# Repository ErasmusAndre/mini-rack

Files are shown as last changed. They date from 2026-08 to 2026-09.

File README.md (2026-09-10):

# mini-rack

The hardware behind [erasmus.works](https://github.com/ErasmusAndre/erasmus.works):
a custom-built 10-inch aluminium mini rack, 3D printed mounts and mains
distribution, and the mini-PCs running my Talos Kubernetes cluster.

<table>
<tr>
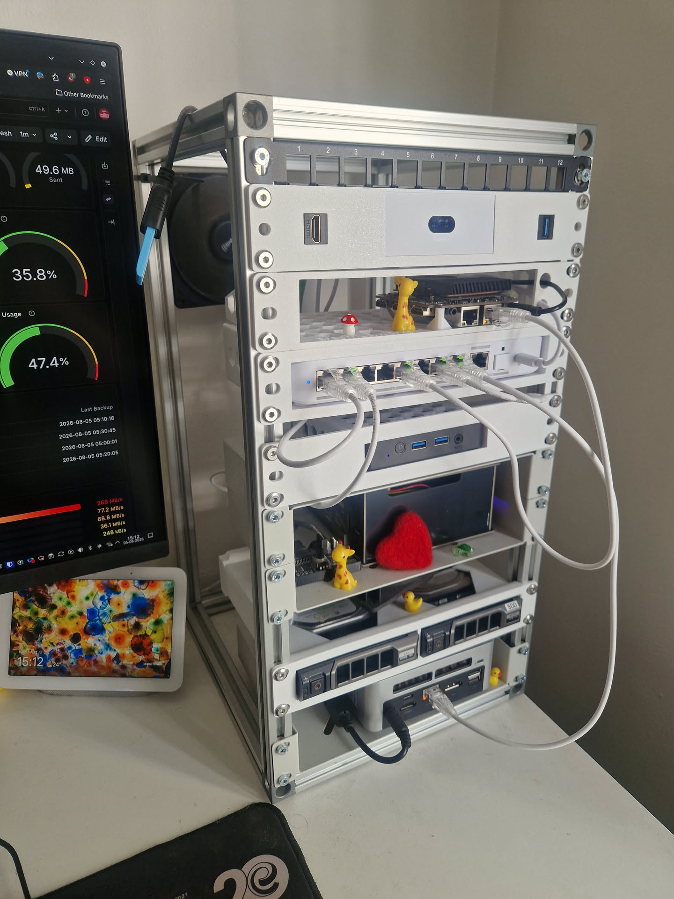
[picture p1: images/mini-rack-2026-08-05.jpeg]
The assembled rack, patch panel at the top down to the nodes and NAS at the bottom
<td width="50%"></td>
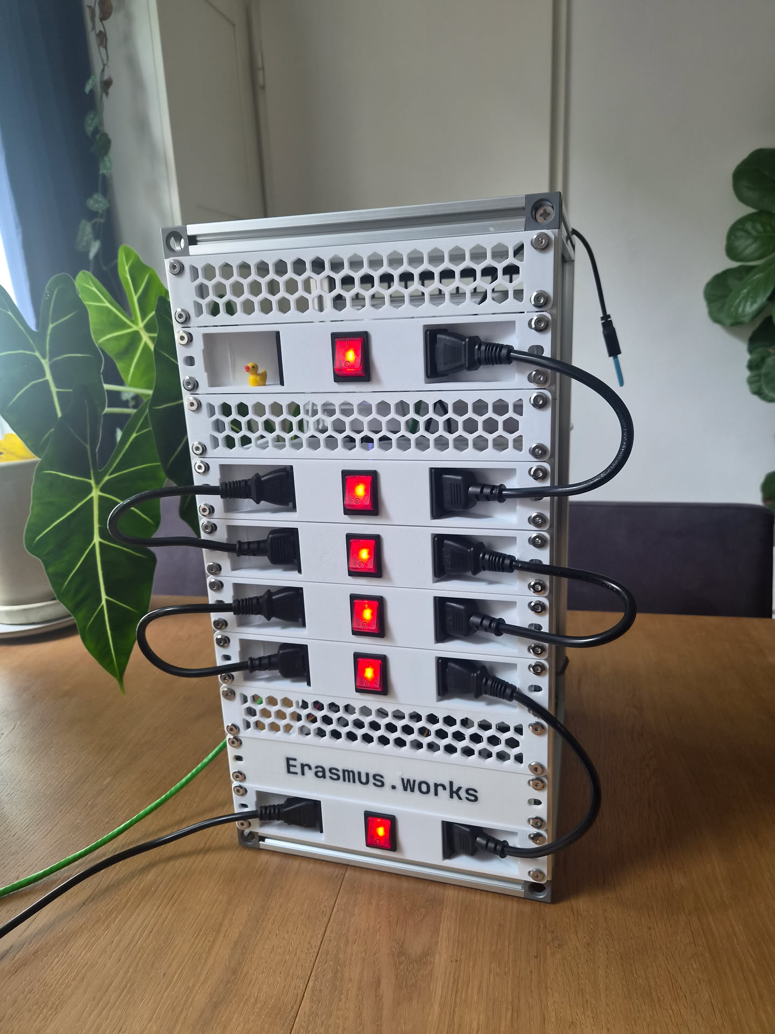
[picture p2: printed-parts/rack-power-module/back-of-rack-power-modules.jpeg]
Six power modules in the back of the rack, rockers lit red, a short cord looping from each module to the one below
<td width="50%"></td>
</tr>
</table>

---

## The Rack

2020 aluminium extrusion, 10U, 220 mm wide and 240 mm deep.

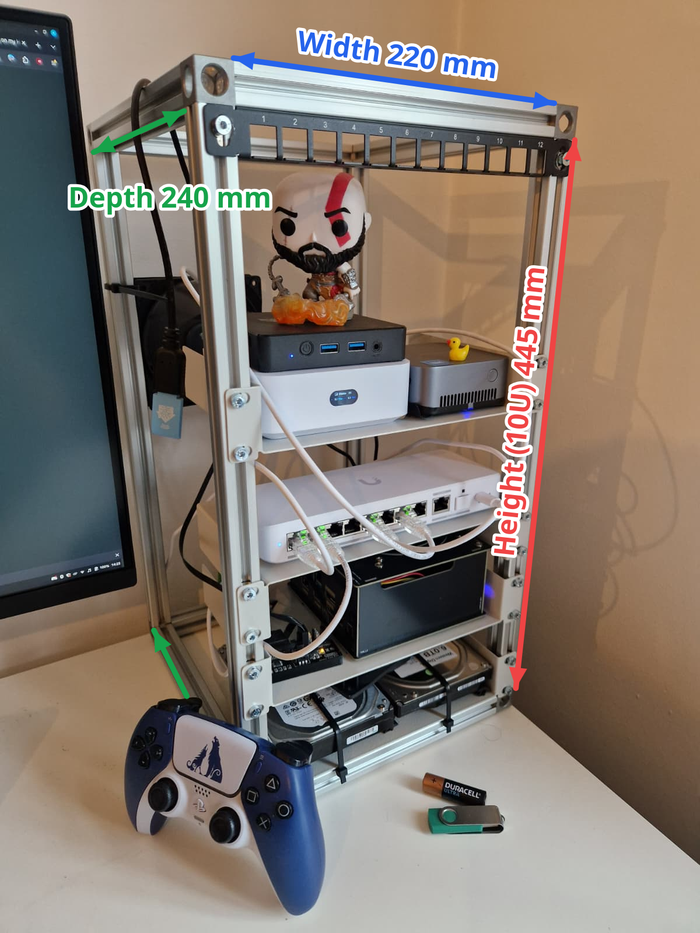
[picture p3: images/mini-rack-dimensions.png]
The rack frame with width 220 mm, depth 240 mm, and 10U height 445 mm marked


*PS5 controller, AA battery and USB stick for scale.*

### Parts

| Qty | Part | Price |
| --- | --- | --- |
| 4 | [Profile 20x20 B-type slot 6](https://www.motedis.nl/en/Profile-20x20-B-type-slot-6), 1 m lengths | €23.00 |
| 8 | [Cube connector 20 B-type slot 6](https://www.motedis.nl/en/Cube-connector-20-B-type-slot-6), 3D variant | €33.00 |
| 40 | [Roll-in T-slot nut, slot 6, M5](https://www.aluxprofiel.nl/inklikmoer-t-sleuf-6-m5/a3665), 4 per U | €10.00 |
| 40 | [Flanged button head screw DIN 7380F, M5x8](https://www.motedis.nl/nl/Flensbout-DIN-7380F/M5x8), one per T-nut | €9.00 |
| | **Total** | **€75.00** |

#### Notes on the Parts:

Slot 6 throughout, which is the common choice at this profile size and carries by
far the widest range of T-nuts and connectors. 
Note: Slot 5 profile and connectors are not interchangeable with these.

Take the 3D connectors, not 2D: every corner of a cuboid frame joins three
profiles. They ship with DIN965 M6x16 countersunk screws, one per profile.

The T-nuts roll into an assembled frame, so mounting points can be added later
without taking the rack apart. Order spares, they are 20 cents each. M5 here is
the nut thread and is unrelated to the profile's M6 core.

The flange spreads load across the slot edges, so no washer is needed in normal
use. M5x8 suits 3 to 5 mm printed parts. For thinner mounts such as 1.5 mm steel
shelves, add a washer or drop to a 6 mm bolt, otherwise the screw bottoms out
before it clamps.

### Cut list

Twelve pieces out of the four 1 m lengths:

| Qty | Length | Axis |
| --- | --- | --- |
| 4 | 220 mm | Width |
| 4 | 240 mm | Depth |
| 4 | 445 mm | Height |

A rack unit is 44.5 mm, so height is `44.5 x U`. This build is 10U: 44.5 x 10 = 445 mm.

Two 445 mm pieces come out of each of the first two lengths, four 240 mm out of
the third, four 220 mm out of the fourth. That is 3620 mm cut from 4000 mm, so
there is room for saw kerf and a mistake.

Depth is a free choice. 240 mm clears the mini-PCs used here with room for cabling
behind them.

<!-- TODO: rack ears and patch panel mounting. -->

## 3D Printed Parts

<!-- TODO: one row per part: what it mounts, filament, and print settings.
     Both exports live in printed-parts/, same basename: rack-ear.step (AP242, from
     Onshape) next to rack-ear.3mf (slicer project, carries the print settings,
     so link it rather than retyping them). Add the public Onshape doc link.
     Ship the STEP where there is one: it is the file people can actually
     edit. CC BY-NC-SA does not require it. -->

| Part | Mounts | Material | Files |
| --- | --- | --- | --- |
| [Blackview MP-80 10 inch rack mount](printed-parts/blackview-mp80-10inch-rack-mount/) | K8s Node 2, 1U on the rails | PLA | [STEP](printed-parts/blackview-mp80-10inch-rack-mount/Blackview-MP80-10inch-Rack-Mount.step) · [3MF](printed-parts/blackview-mp80-10inch-rack-mount/Blackview-MP80-10inch-Rack-Mount.3mf) |
| [Blackview MP-80 mount](printed-parts/blackview-mp80-mount/) | K8s Node 2, shelf test mount | PLA | [STEP](printed-parts/blackview-mp80-mount/Blackview-MP80-Mount.step) · [3MF](printed-parts/blackview-mp80-mount/Blackview-MP80-Mount.3mf) |
| [Rack power module](printed-parts/rack-power-module/) | Mains distribution, 1U on the rails | PLA | [3MF, both variants](printed-parts/rack-power-module/README.md#files) |

## Power

One printed module per device, stacked down the back of the rack. Each carries a
C14 inlet, an illuminated DPST rocker and a C13 outlet, with a honeycomb shelf
behind the face plate for the device's mains adapter. A 30 cm C13 to C14 cord
links each module to the one below, so the stack chains off a single feed and
each rocker cuts its own module and everything downstream.

Two variants share the same face plate. **DIN rail** takes a normal two pin wall
plug on a length of DIN rail. **Power brick** goes straight into the brick's C14
inlet on a right angle connector. Stacked, the sockets alternate left and right,
which leaves room for an adapter taller than 1U.

Each module is 1U at the rails and costs €16 to €18 in parts.

<table>
<tr>
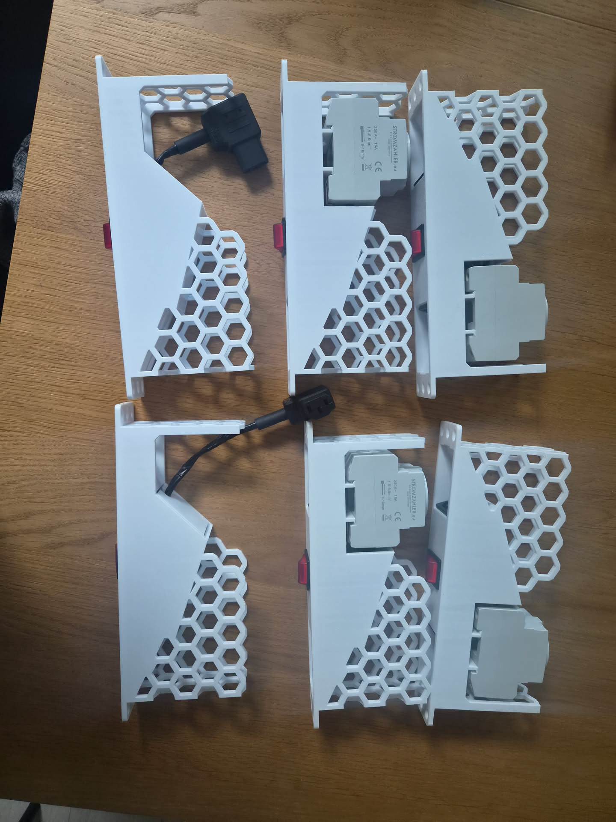
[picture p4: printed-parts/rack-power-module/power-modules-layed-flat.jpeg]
Six modules laid flat on a table, showing the face plate, the honeycomb side wall and the shelf, four with a DIN rail socket and two with a right angle C13 connector
<td width="50%"></td>
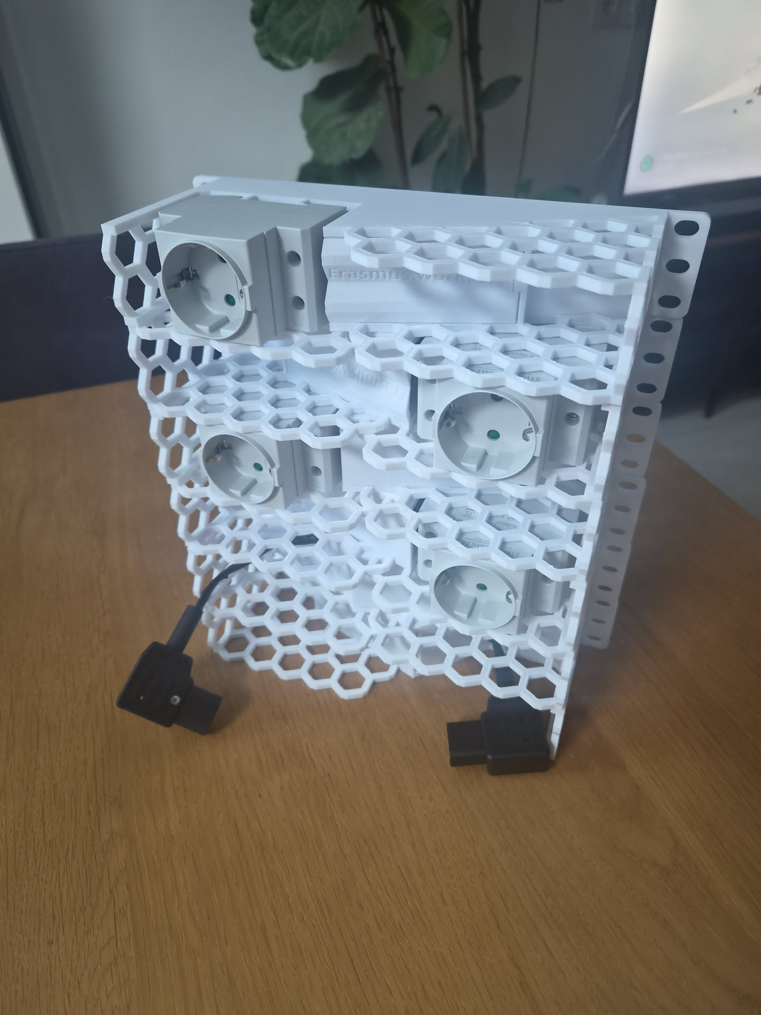
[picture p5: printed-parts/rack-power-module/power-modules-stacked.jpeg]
Four modules stacked, sockets alternating left and right down the stack, each clipped to the DIN rail behind the honeycomb shelf
<td width="50%"></td>
</tr>
</table>

This part carries live mains, which kills people who get it wrong. Do not build
it unless you are competent to wire mains and permitted to do so where you live.
Read [Safety](printed-parts/rack-power-module/README.md#safety) before you start,
and before you pick a filament.

Bill of materials, wiring diagram and build steps:
[Rack Power Module](printed-parts/rack-power-module/).

## Hardware

Compute currently in the cluster:

| Hardware | Model | CPU | Memory | Storage |
| --- | --- | --- | --- | --- |
| K8s Node 1 | MINIS FORUM UN1245 Mini-PC | Intel Core i5-12450H | 16 GB DDR4 | 512 GB SSD |
| K8s Node 2 | Blackview MP-80 | Intel Processor N97 | 16 GB DDR5 | 512 GB SSD |
| Home Assistant | BMAX B2 Pro | Intel Celeron N4000 | 8 GB DDR4 | 256 GB SSD |
| NAS | ODROID-H4+ | Intel Processor N97 | 16 GB DDR5 | 2 × 6 TB HDD |
| Router | UniFi Express 7 (UX7) | - | - | - |
| Switch | UniFi Flex 2.5G (USW-Flex-2.5G-8) | - | - | - |

---

## License

Star ⭐ this repo if you found it useful.

[CC BY-NC-SA 4.0](LICENSE). Use it, modify it, share it, as long as you credit
Erasmus.works, link back to this repo, keep it non-commercial, and license
anything you share under the same terms.

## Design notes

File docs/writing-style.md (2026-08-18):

# Writing style

Applies to every README, part doc, and comment in this repo.

## Length

Say it once. Cut any sentence that repeats, summarises, or softens the one
before it. If a section survives losing a sentence, lose it.

Document decisions and facts, not reasoning you can infer from the result. The
reader wants to print the part, not follow how it was designed.

## Preferred

Facts over descriptions of facts. Write "0.2 mm layers", not "a fairly standard
layer height".

Imperative for instructions. "Keep the OEM screws", not "you will want to keep
the OEM screws".

Three items in a list only when there are three things.

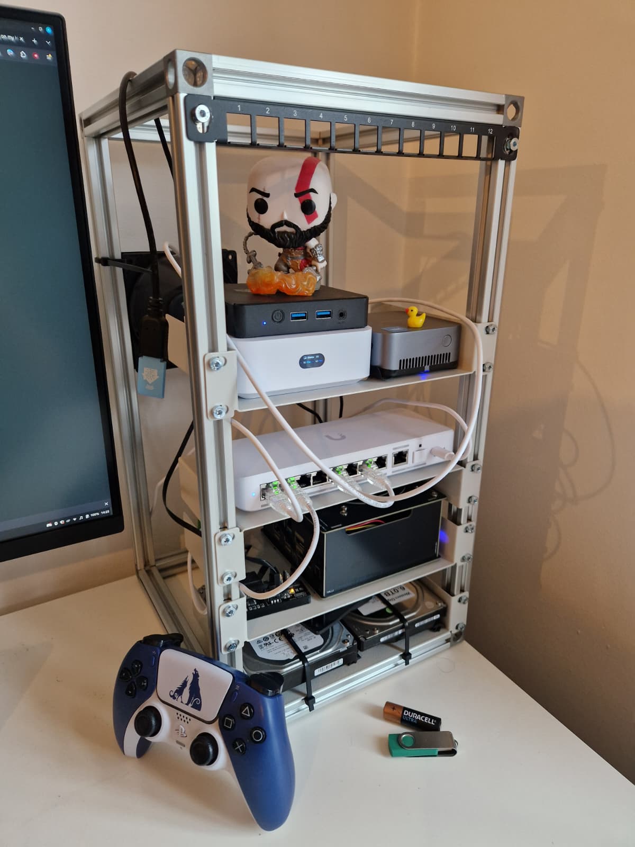
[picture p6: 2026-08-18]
images/mini-rack-2025-10-10.jpeg

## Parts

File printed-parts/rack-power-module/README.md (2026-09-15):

# Rack Power Module

A 10-inch rack part for mains distribution: one switched socket per module,
chained down the back of the rack.

Do not build this without reading [Safety](#safety) first.

Six power modules in the back of the rack, rockers lit red, a short cord looping from each module to the one below

## Design notes

These are the modules. Two variants, same face plate: C14 inlet, illuminated
rocker, C13 outlet, and a honeycomb shelf behind it for the mains adapter. A
30 cm C13 to C14 cord links each module to the next.

**Power brick**, the two at the left below: a rewireable right angle C13
connector, straight into the brick's C14 inlet.

**DIN rail**: a socket on a length of DIN rail, for a normal two pin wall
plug.

<table>
<tr>
<td width="50%">Six modules laid flat on a table, showing the face plate, the honeycomb side wall and the shelf, four with a DIN rail socket and two with a right angle C13 connector</td>
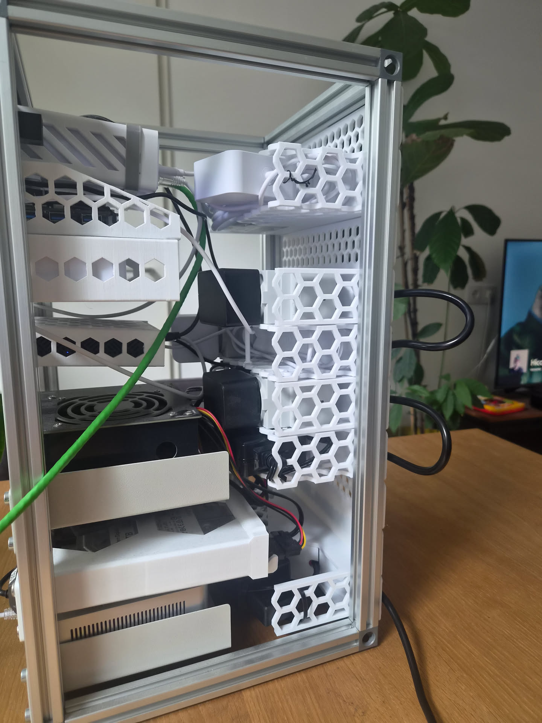
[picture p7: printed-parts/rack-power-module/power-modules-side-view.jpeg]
The rack from the side, power modules stacked down the right, adapters resting on the honeycomb shelves
<td width="50%"></td>
</tr>
</table>

Stacked, the sockets alternate left and right. A rack unit is 44.5 mm and some
wall plugs are taller than that, so the offset leaves room for a big one.

Both print files include a cable clip, a fork that pushes into the honeycomb.
Roll the slack up and hold it there.

Four modules stacked, sockets alternating left and right down the stack, each clipped to the DIN rail behind the honeycomb shelf

## Hardware

Per module:

| Qty | Part | Price | Mounting |
| --- | --- | --- | --- |
| 1 | [C13 to C14 cord, 30 cm](https://nl.rs-online.com/web/p/power-cords/1373334) (RS 1373334) | €4.95 | |
| 1 | [C14 inlet, snap-in](https://nl.rs-online.com/web/p/iec-connectors/5392023) (Schurter 6100.4320) | €1.15 | 27.5 × 20.0 mm cutout |
| 1 | [C13 outlet, snap-in](https://nl.rs-online.com/web/p/iec-connectors/5392152) (Schurter 6600.4315) | €2.15 | 32.5 × 24.8 mm cutout |
| 1 | [Illuminated DPST rocker](https://nl.rs-online.com/web/p/rocker-switches/7932507) (Molveno SX82) | €1.75 | 30 × 22 mm cutout |
| 8 | [Female faston, insulated, 0.5 to 1.5 mm²](https://nl.rs-online.com/web/p/spade-connectors/0534339) (RS 534-339) | €1.45 | 6.3 × 0.8 mm tabs |
| 0.6 m | H05VV-F 3G1.5 flexible cable | €0.80 | |
| | **Subtotal** | **€12.25** | |

Plus, per variant:

| Variant | Part | Price | Total |
| --- | --- | --- | --- |
| DIN rail | [DIN rail socket](https://stromzähler.eu/detail/018af08cc9277014a5bf7629857d9ec8) (B+G E-Tech) + 2 × [twin ferrule](https://nl.rs-online.com/web/p/bootlace-ferrules/1788742) (RS 178-8742) | €3.85 | €16.10 |
| Power brick | [C13 rewireable, right angle](https://nl.rs-online.com/web/p/iec-connectors/2825502) (RS 282-5502) + 2 × [butt splice](https://nl.rs-online.com/web/p/splice-connectors/2707457) (RS 270-7457) | €5.48 | €17.73 |

## Want to build this yourself?

1. Download the [print files](#files) and print what you need.
2. Star this repo ⭐
3. Clip in the C13 and C14 connectors, 2 prongs facing away from the face plate.
4. Alternate the rocker per module to keep every switch facing the same way.
5. Wire it up as in [Wiring](#wiring).
6. Clip in and wire up the DIN rail socket or the C13 plug.
7. Clip in the closing plates, short one first. Spread the honeycomb if it sticks.

## Wiring

Do not build this without reading [Safety](#safety) first.

Live and neutral both break at the rocker.

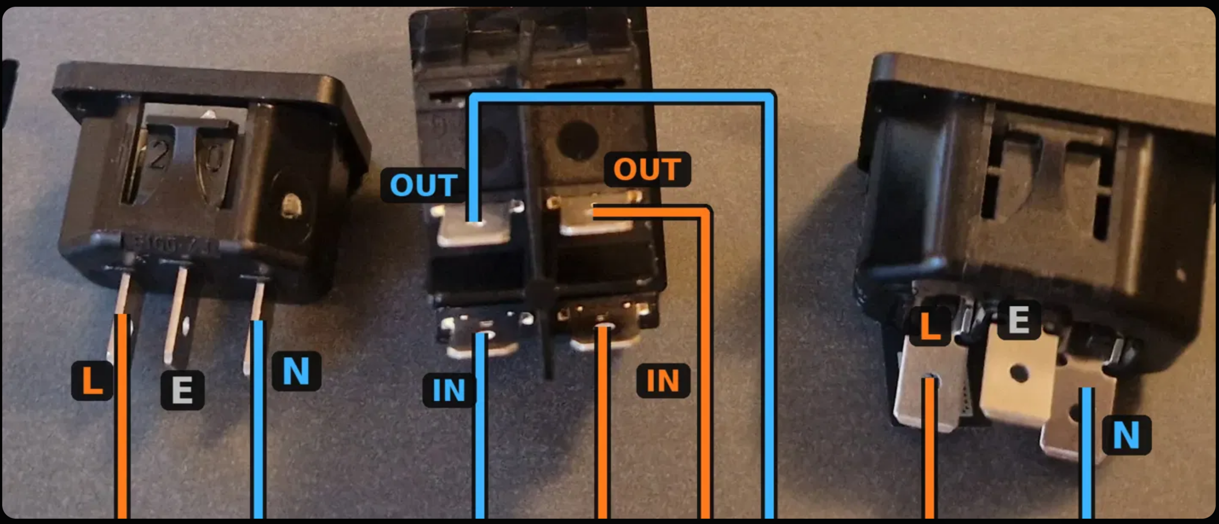
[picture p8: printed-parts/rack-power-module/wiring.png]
C14 inlet on the left, DPST rocker in the middle, C13 outlet on the right, live traced in orange and neutral in blue


Run live and neutral from the inlet to the rocker and nowhere else. Socket and
outlet both come off the switched side, so the rocker cuts this module and
everything downstream.

The socket splits off after the rocker: at the socket on the DIN rail variant,
two wires into one twin ferrule; mid lead on the power brick variant, at a butt
splice.

<table>
<tr>
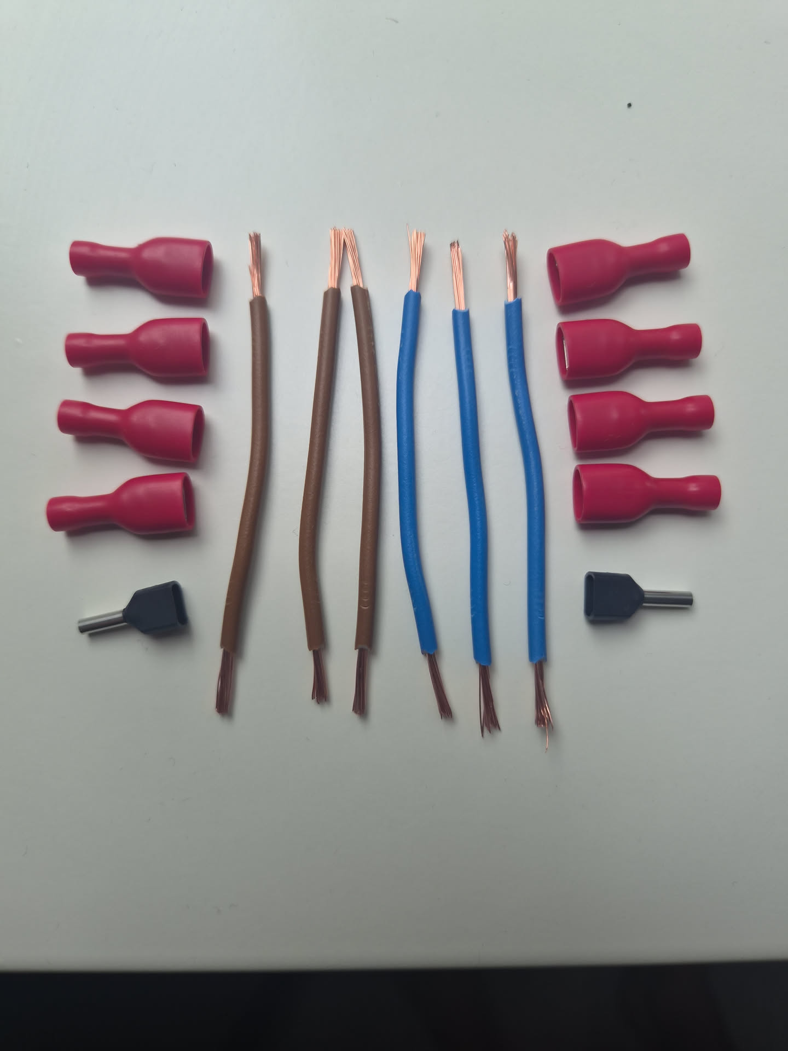
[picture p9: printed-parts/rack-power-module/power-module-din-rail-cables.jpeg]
Eight insulated female fastons, six short leads in brown and blue, and two twin ferrules
<td width="50%"></td>
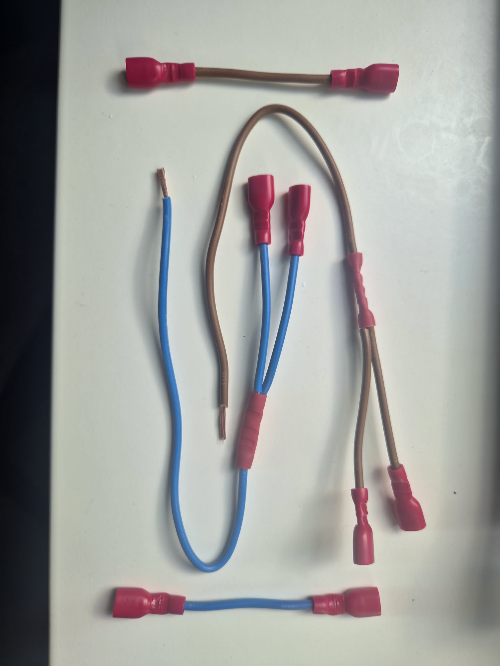
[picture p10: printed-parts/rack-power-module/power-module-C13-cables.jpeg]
Longer brown and blue leads crimped with insulated fastons, a red butt splice partway along the brown pair and another along the blue
<td width="50%"></td>
</tr>
<tr>
<td><em>DIN rail loom. Cut all six leads to 8 cm. Twin ferrules at the socket.</em></td>
<td><em>Power brick loom. Cut four leads to 8 cm and one to about 16 cm. Butt splices for the split.</em></td>
</tr>
</table>

Wired up, before the variant-specific parts go in, it looks like this.

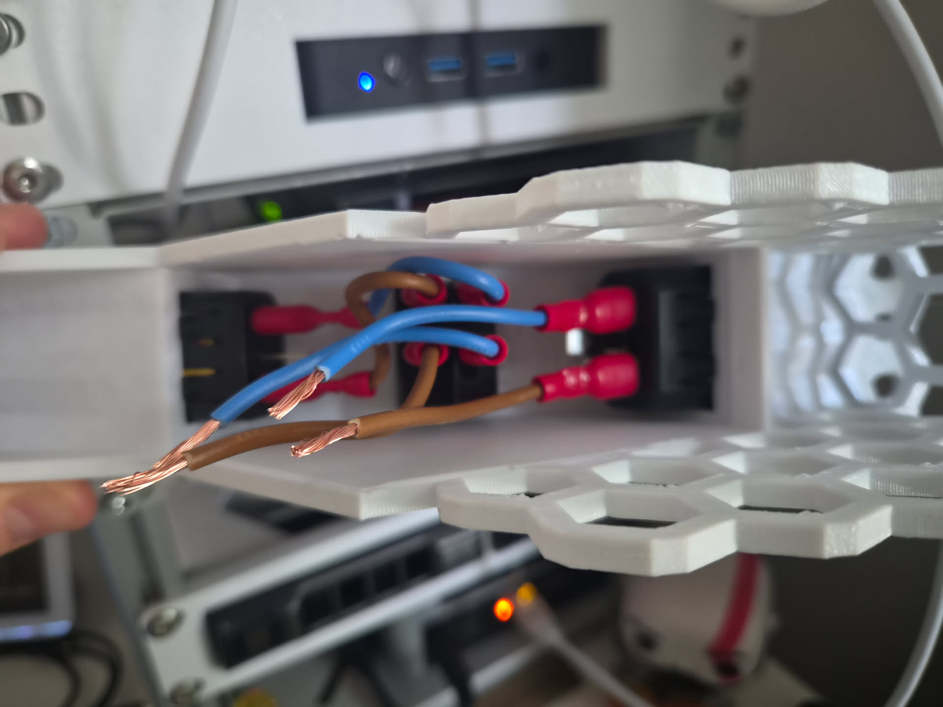
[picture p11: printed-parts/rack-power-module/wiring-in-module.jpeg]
The back of a face plate, brown and blue leads crimped onto the connectors and the rocker, free ends waiting for the socket or plug


Alternatively, wire the C13 outlet straight to the C14 inlet and only the socket
through the rocker. The rocker then cuts only what is plugged into this module,
and the modules chained below stay on.

### Daisy chaining

Every connection adds resistance. With quality parts and correct crimps it is
negligible: six chained modules measure 0.2 Ω, the same as a shop-bought rack
power strip. Both read 0.6 Ω on the meter, 0.2 Ω after subtracting 0.4 Ω for the leads.

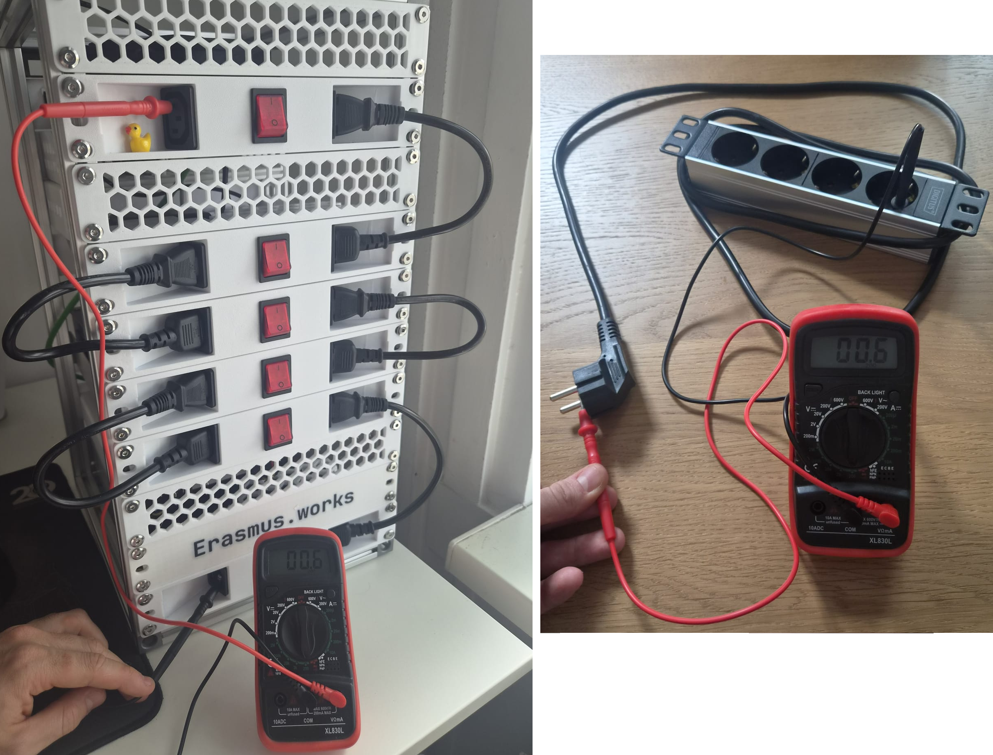
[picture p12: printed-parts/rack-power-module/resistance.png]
Left: a multimeter reading 0.6 Ω across six chained modules. Right: the same meter reading 0.6 Ω across a rack power strip, plug to socket


Measure the resistance before plugging anything in.

## Tools

- 3D printer
- Wire stripper and crimper
- Side cutters
- Long nose pliers
- Screwdriver
- Insulation tape

## Files

Print it in a flame retardent UL 94 V-0 filament such as
[PETG FR Jet](https://shop.filament-pm.com/petg-frjet-self-extinguishing-white-1-75-mm-0-5-kg/p166).

| Variant | File |
| --- | --- |
| DIN rail | [3MF](erasmus-works-power-module-din-rail-v62.3mf) |
| Power brick | [3MF](erasmus-works-power-module-power-brick-v62.3mf) |

## Safety

This part carries live mains. Mains wiring kills people who get it wrong, and a
fault in a printed enclosure can start a fire.

Do not build it unless you are competent to wire mains and permitted to do so
where you live. Sleeve or shroud all live terminals.
PLA softens around 60 °C, PETG around 80 °C. Neither is flame retardant. Only a
UL 94 V-0 filament is. Print it in a self-extinguishing filament such as
[PM PETG FR Jet](https://shop.filament-pm.com/petg-frjet-self-extinguishing-white-1-75-mm-0-5-kg/p166).

Wire the protective earth if anything you plug in needs it.

Every module draws its power through the ones before it, so the first module
carries the load of the whole chain. Keep the total under 10 A, 2300 W at
230 V: that is the rating of the C13 and C14 connectors and the 0.75 mm² cords.

Build it at your own risk. I take no responsibility for injury, death, fire, or
damage resulting from anything in this repository.

## License

Star ⭐ this repo if you found it useful.

[CC BY-NC-SA 4.0](../../LICENSE). Use it, modify it, share it, as long as you
credit Erasmus.works, link back to this repo, keep it non-commercial, and
license anything you share under the same terms.

This work is offered as is, WITHOUT WARRANTIES OR CONDITIONS OF ANY KIND,
express or implied. Please see the licence for applicable conditions.

Source location: https://github.com/ErasmusAndre/mini-rack

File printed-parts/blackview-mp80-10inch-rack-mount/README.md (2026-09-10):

# Blackview MP-80 10 inch Rack Mount

A 1U 10-inch tray for the Blackview MP-80 (K8s Node 2) with its OEM enclosure
stripped off, printed in white PLA.

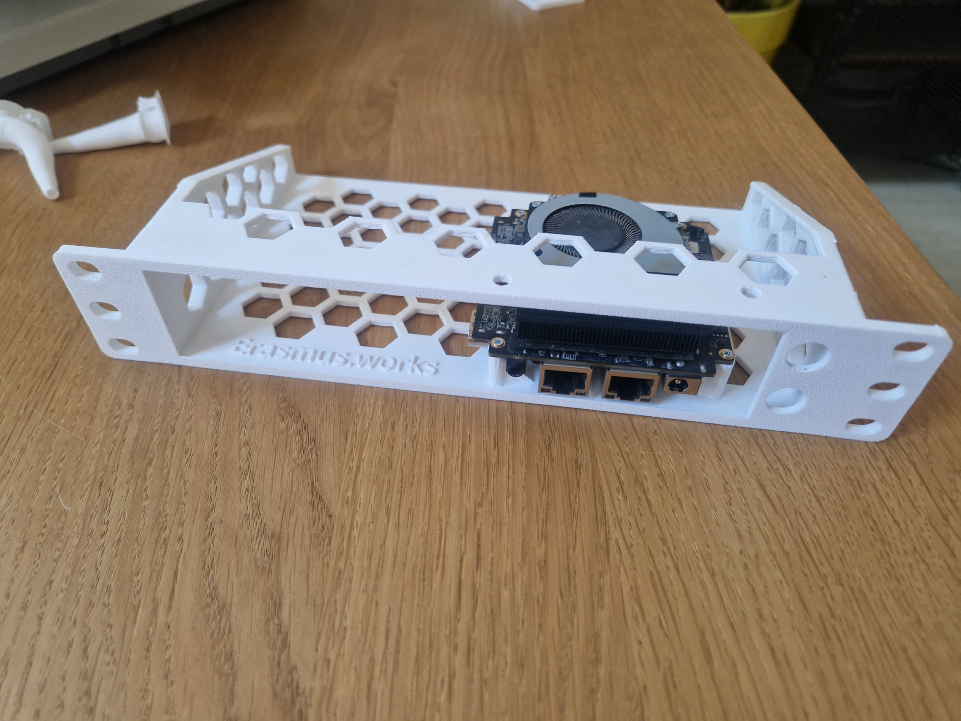
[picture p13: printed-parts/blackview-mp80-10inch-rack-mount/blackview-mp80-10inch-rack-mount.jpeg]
The printed tray on a desk with the bare MP-80 board bolted in


## Design notes

The board no longer sits on a shelf. This is what the
[test mount](../blackview-mp80-mount/) was a trial run for: the same board
profile, now folded into a full-width tray.

The MP-80 does not go in the rack in its OEM enclosure. The board comes out of
the case and bolts to the tray instead. Outside the sealed plastic shell the
heatsink sits in open air, so the node runs cooler.

The hex cutouts in the floor and side wall let air through and cut print time.
The front panel carries embossed Erasmus.works text, the files you can download in this repo don't. 

## Printing

Print the front panel face down on the bed, with tree supports.

## Hardware

| Qty | Part |
| --- | --- |
| 4 | Flanged button head DIN 7380F, M5x8, one per ear hole |
| 4 | Roll-in T-slot nut, slot 6, M5 |
| | The MP-80's own enclosure screws, salvaged when you strip the case |

## Files

| File | What it is |
| --- | --- |
| [`Blackview-MP80-10inch-Rack-Mount.step`](Blackview-MP80-10inch-Rack-Mount.step) | Source geometry, STEP AP242. Edit this. |
| [`Blackview-MP80-10inch-Rack-Mount.3mf`](Blackview-MP80-10inch-Rack-Mount.3mf) | Ready to slice and print. |

## License

Star ⭐ this repo if you found it useful.

[CC BY-NC-SA 4.0](../../LICENSE). Use it, modify it, share it, as long as you
credit Erasmus.works, link back to this repo, keep it non-commercial, and
license anything you share under the same terms.

This work is offered as is, WITHOUT WARRANTIES OR CONDITIONS OF ANY KIND,
express or implied. Please see the licence for applicable conditions.

Source location: https://github.com/ErasmusAndre/mini-rack

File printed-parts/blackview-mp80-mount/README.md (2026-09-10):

# Blackview MP-80 Mount

A stand for the Blackview MP-80 (K8s Node 2) with its OEM enclosure stripped
off, printed in green PLA.

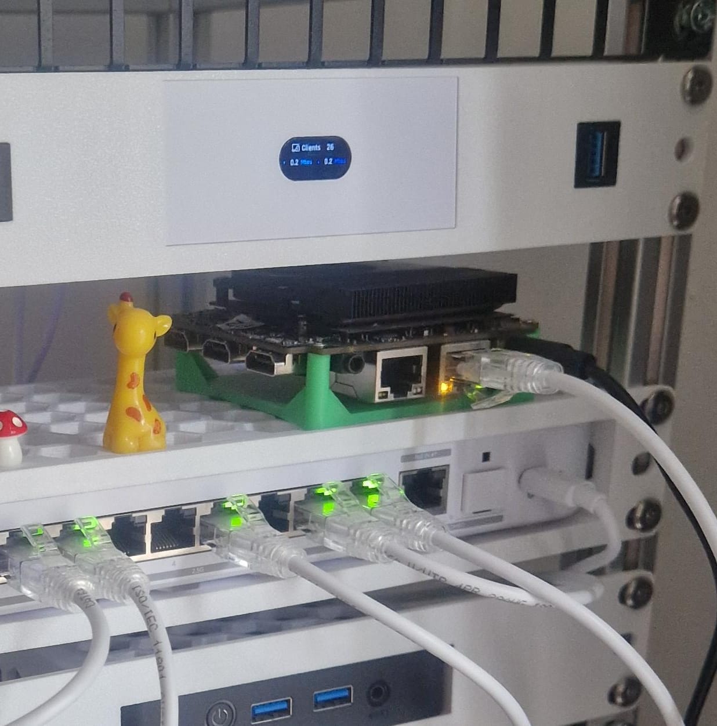
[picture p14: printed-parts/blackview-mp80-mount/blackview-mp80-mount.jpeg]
The mount in the rack, holding the bare MP-80 board


## Design notes

This is a test mount, not a finished part. It holds the board steady on a shelf
and nothing more. The profile was folded into the
[10 inch rack mount](../blackview-mp80-10inch-rack-mount/), which is what the
node runs in now.

The MP-80 does not go in the rack in its OEM enclosure. The board comes out of
the case and bolts to this stand instead. Outside the sealed plastic shell the
heatsink sits in open air, so the node runs cooler, and without the case it
takes up much less room on the shelf.

The screws that hold the board down come from the OEM enclosure, so keep them
when you take the case apart. Nothing else is needed.

## Printing

It lays flat on its bottom face and prints without supports.

## Hardware

The MP-80's own enclosure screws, salvaged when you strip the case. No other
fasteners.

## Files

| File | What it is |
| --- | --- |
| [`Blackview-MP80-Mount.step`](Blackview-MP80-Mount.step) | Source geometry, STEP AP242. Edit this. |
| [`Blackview-MP80-Mount.3mf`](Blackview-MP80-Mount.3mf) | Ready to slice and print. |

## License

Star ⭐ this repo if you found it useful.

[CC BY-NC-SA 4.0](../../LICENSE). Use it, modify it, share it, as long as you
credit Erasmus.works, link back to this repo, keep it non-commercial, and
license anything you share under the same terms.

This work is offered as is, WITHOUT WARRANTIES OR CONDITIONS OF ANY KIND,
express or implied. Please see the licence for applicable conditions.

Source location: https://github.com/ErasmusAndre/mini-rack

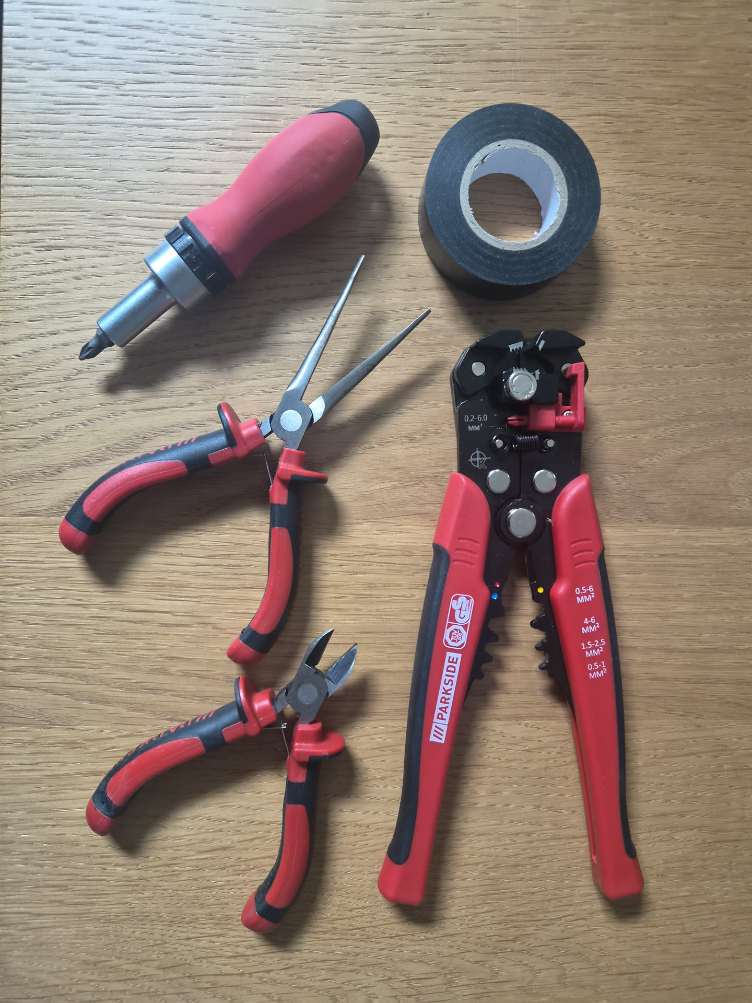
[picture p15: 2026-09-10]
printed-parts/rack-power-module/tools-needed.jpeg

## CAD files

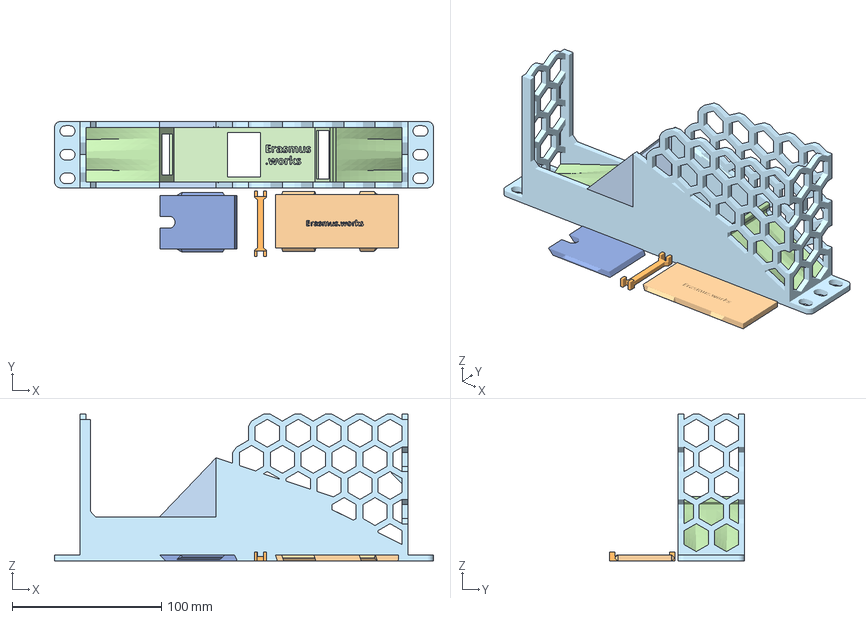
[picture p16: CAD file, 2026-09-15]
printed-parts/rack-power-module/erasmus-works-power-module-power-brick-v62.3mf
254.0 x 90.5 x 98.4 mm
Cable Clip
Mount Switch
right chamfer
Left power plate
Left chamfer
Mount C13
Mount C14
hinge plate
extend front plate
extend back plate
Face-Plate

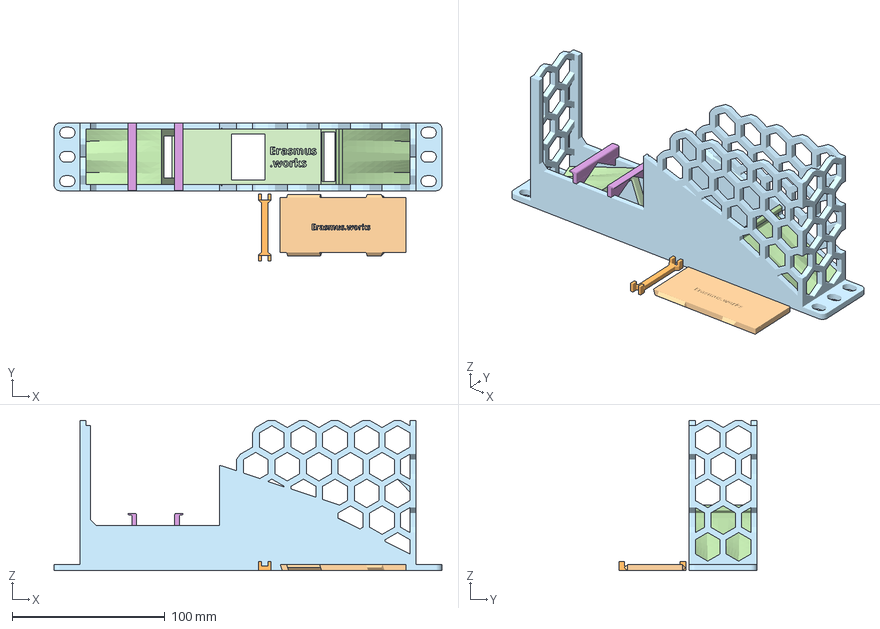
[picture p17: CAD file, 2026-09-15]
printed-parts/rack-power-module/erasmus-works-power-module-din-rail-v62.3mf
254.0 x 90.5 x 98.4 mm
DIN Rail right
DIN Rail left
Cable Clip
Mount Switch
right chamfer
Left chamfer
Mount C13
Mount C14
Face-Plate
hinge plate

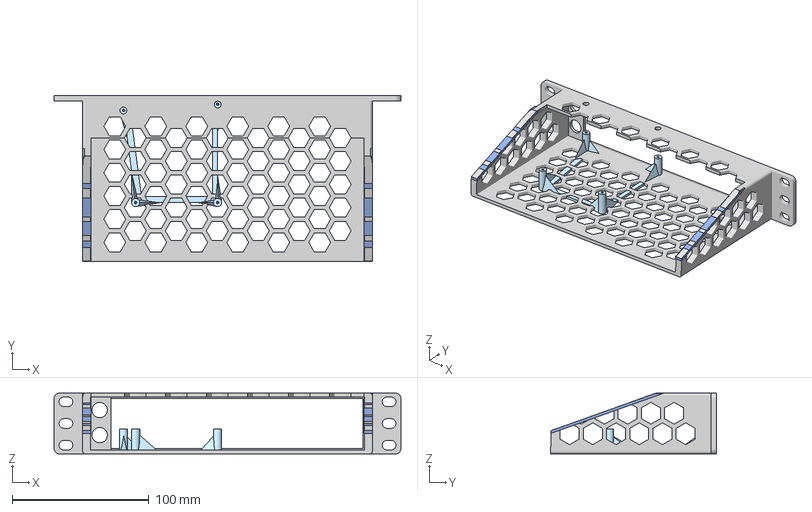
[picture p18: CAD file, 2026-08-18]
printed-parts/blackview-mp80-10inch-rack-mount/Blackview-MP80-10inch-Rack-Mount.step
254.0 x 121.4 x 44.5 mm

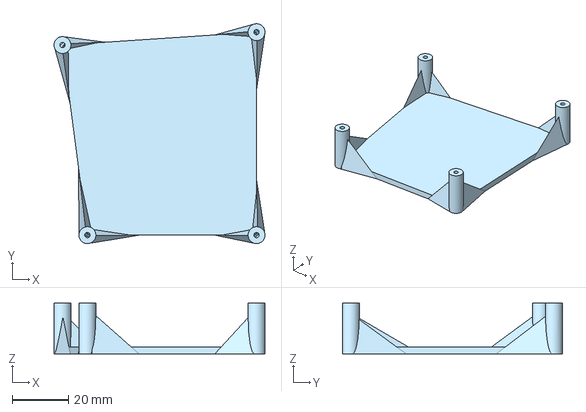
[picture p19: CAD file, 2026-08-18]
printed-parts/blackview-mp80-mount/Blackview-MP80-Mount.step
74.8 x 78.1 x 18.0 mm

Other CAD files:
printed-parts/blackview-mp80-10inch-rack-mount/Blackview-MP80-10inch-Rack-Mount.3mf
printed-parts/blackview-mp80-mount/Blackview-MP80-Mount.3mf

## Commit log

2026-08-18 Add 10 inch MP-80 rack mount
    [Blackview-MP80-10inch-Rack-Mount.3mf, Blackview-MP80-10inch-Rack-Mount.step]
2026-08-20 add WIP rack-power-module
2026-08-22 cleanup print module readme
2026-08-22 add safety notice on power module
2026-09-10 Relicense to CC BY-NC-SA 4.0 before publishing power module
2026-09-10 Add everythign except 3mf and stl files of Power-Module
2026-09-10 update readme power module
2026-09-12 update safety before sharing print files
2026-09-15 Add CAD / 3D files for power module, and update wiring section of README
    [erasmus-works-power-module-din-rail-v62.3mf, erasmus-works-power-module-power-brick-v62.3mf]
2026-09-15 Add note about Resistance.
